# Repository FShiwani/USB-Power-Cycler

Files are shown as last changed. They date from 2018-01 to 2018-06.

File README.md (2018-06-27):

# USB Power Cycler
A design using an ATMega328P-PU microcontroller to delay the supply of power to an external USB device. It is useful for sensitive USB devices that cannot handle rapid switches in power.

## Purpose
The reason behind the design was to delay the start up of a USB car handsfree receiver that would stop functioning due to power being cycling to the device when switching from the ACC to ON ignition states.

## Design Information
The choice of the microcontroller may seem a slightly too advanced for this project however due to it's popularity and the fact that the Arduino Uno boards use the exact same MCU I chose it to allow a smooth transition between my Arduino prototype over to an independant MCU using the internal 8MHz clock. Depending on how you source your ATMega328P-PU it may come preloaded with a bootloader designed for a 16MHz external crystal such as in the Arduino Uno or it may come with no bootloader burned at all. Either way, you will need to use a different bootloader with the approparite fuses enabled to use the internal clock. More information can be found [here](https://www.arduino.cc/en/Tutorial/ArduinoToBreadboard). An 8-bit DIP switch is used to control the delay time. Values from 0 to 255 seconds are possible with the 8-bits and must be used in binary form. The firmware loaded on the MCU is relatively straight forward and an Arduino sketch is also available. The FDN340P is a logic level p-channel MOSFET is being used as a high side switch for the 5V rail.

## Schematic View
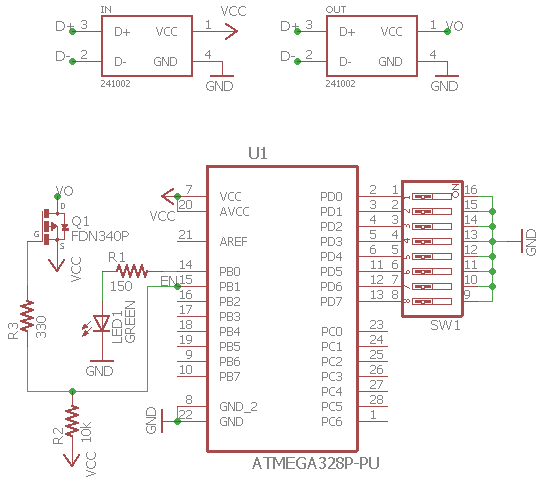
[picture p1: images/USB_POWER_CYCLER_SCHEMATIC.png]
Schematic

## Board View
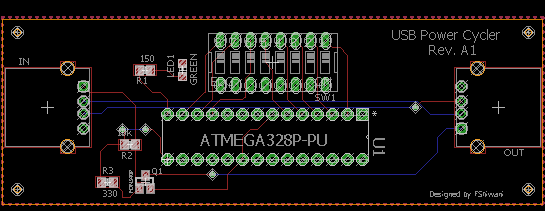
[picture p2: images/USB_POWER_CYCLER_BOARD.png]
Board


## Final Images
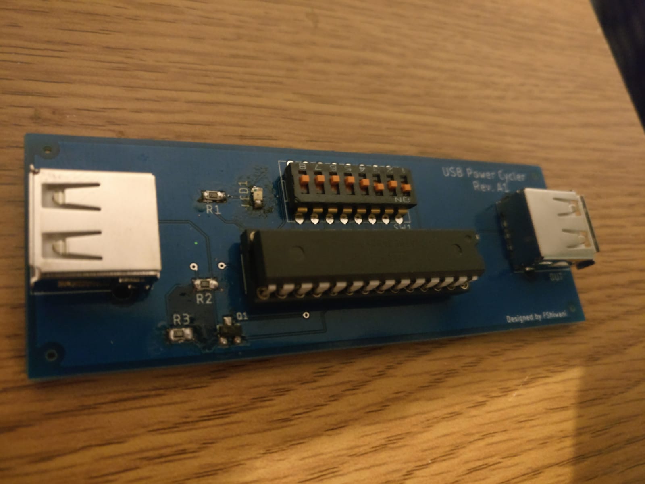
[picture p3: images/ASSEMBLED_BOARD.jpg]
Final Board

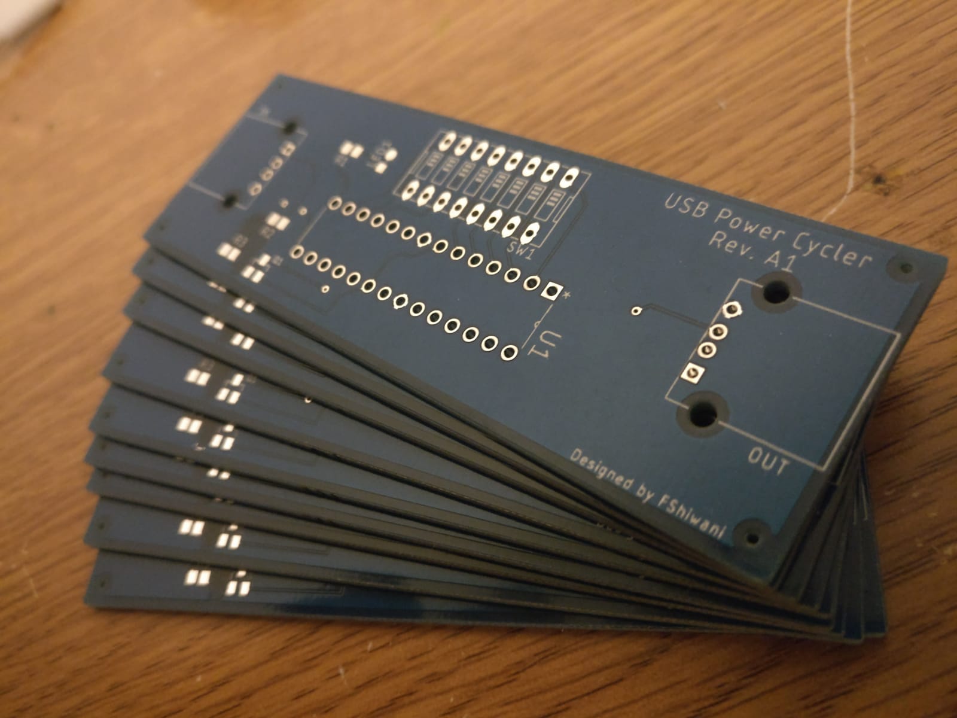
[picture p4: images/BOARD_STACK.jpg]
PCBs


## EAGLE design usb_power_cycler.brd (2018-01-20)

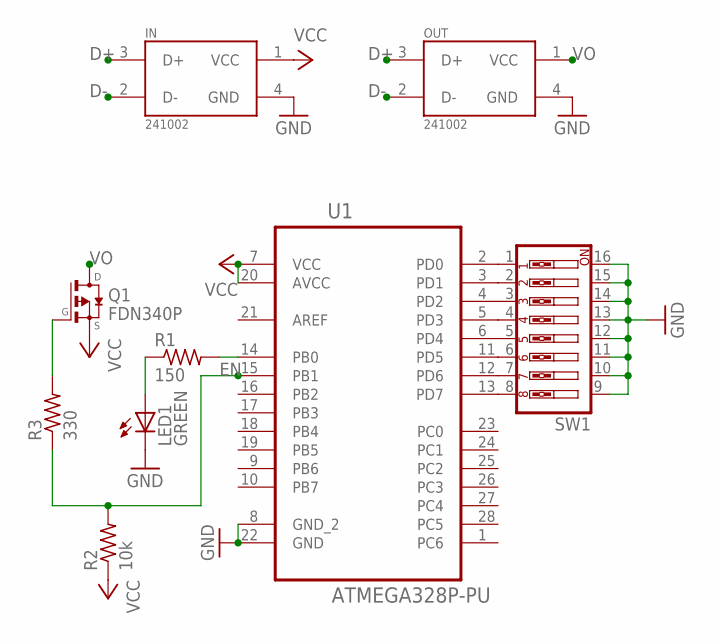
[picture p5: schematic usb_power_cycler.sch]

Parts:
IN: 241002; LUMBERG_2410_02
LED1: GREEN; CHIPLED_0805
OUT: 241002; LUMBERG_2410_02
Q1: FDN340P; SSOT-3
R1: 150; R0805
R2: 10k; R0805
R3: 330; R0805
SW1: SW_DIP-8; EDG-08
U1: ATMEGA328P-PU; DIP254P762X457-28

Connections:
D+: IN.3 (D+), OUT.3 (D+)
D-: IN.2 (D-), OUT.2 (D-)
EN: R2.2, R3.1, U1.15 (PB1)
GND: IN.4 (GND), LED1.C, OUT.4 (GND), SW1.9, SW1.10, SW1.11, SW1.12, SW1.13, SW1.14, SW1.15, SW1.16, U1.8 (GND_2), U1.22 (GND)
unnamed: LED1.A, R1.1
unnamed: SW1.1, U1.2 (PD0)
unnamed: SW1.2, U1.3 (PD1)
unnamed: SW1.3, U1.4 (PD2)
unnamed: SW1.4, U1.5 (PD3)
unnamed: SW1.5, U1.6 (PD4)
unnamed: SW1.6, U1.11 (PD5)
unnamed: SW1.7, U1.12 (PD6)
unnamed: SW1.8, U1.13 (PD7)
unnamed: R1.2, U1.14 (PB0)
unnamed: Q1.1 (G), R3.2
VCC: IN.1 (VCC), Q1.2 (S), R2.1, U1.7 (VCC), U1.20 (AVCC)
VO: OUT.1 (VCC), Q1.3 (D)

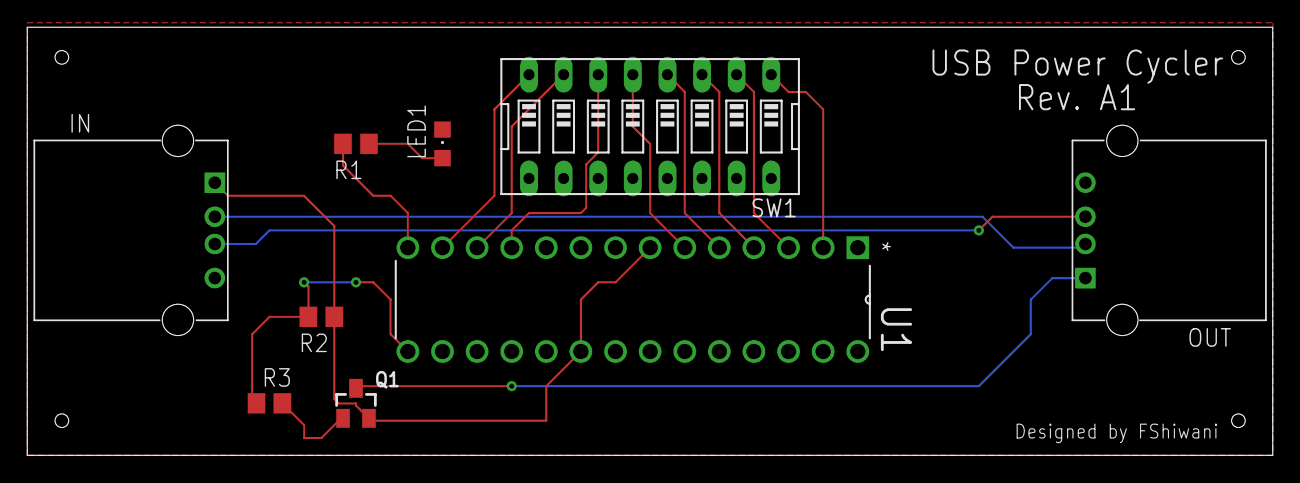
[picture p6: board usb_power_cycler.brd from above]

Board: 2 copper layers, 91.4 x 31.4 mm, 9 parts (0 on the bottom side), 17 nets.

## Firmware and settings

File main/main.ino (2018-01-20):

// ▒█░▒█ ▒█▀▀▀█ ▒█▀▀█ ░░ ▒█▀▀█ ▒█▀▀▀█ ▒█░░▒█ ▒█▀▀▀ ▒█▀▀█ ░░ ▒█▀▀█ ▒█░░▒█ ▒█▀▀█ ▒█░░░ ▒█▀▀▀ ▒█▀▀█ 
// ▒█░▒█ ░▀▀▀▄▄ ▒█▀▀▄ ▀▀ ▒█▄▄█ ▒█░░▒█ ▒█▒█▒█ ▒█▀▀▀ ▒█▄▄▀ ▀▀ ▒█░░░ ▒█▄▄▄█ ▒█░░░ ▒█░░░ ▒█▀▀▀ ▒█▄▄▀ 
// ░▀▄▄▀ ▒█▄▄▄█ ▒█▄▄█ ░░ ▒█░░░ ▒█▄▄▄█ ▒█▄▀▄█ ▒█▄▄▄ ▒█░▒█ ░░ ▒█▄▄█ ░░▒█░░ ▒█▄▄█ ▒█▄▄█ ▒█▄▄▄ ▒█░▒█ 
/* --------------------------------------------------------------------------------------------------------------------------------------------
 *  Project: USB Power Cycler
 *  Author: Fahd Shiwani
 *  Version: Rev. A
 *  Target Microncontroller: ATMega328P-PU
 * --------------------------------------------------------------------------------------------------------------------------------------------
 */

// Pin Declarations
#define ACTIVITY_LED_PIN 8 // PB0
#define ENABLE_PIN 9 // PB1
#define SW_PIN_1 0 // PD0
#define SW_PIN_2 1 // PD1
#define SW_PIN_3 2 // PD2
#define SW_PIN_4 3 // PD3
#define SW_PIN_5 4 // PD4
#define SW_PIN_6 5 // PD5
#define SW_PIN_7 6 // PD6
#define SW_PIN_8 7 // PD7

unsigned int SW_STATE[8]; // DIP switch state

// function to read digital pins for DIP switch.
void readSWState(int SW_STATE[]){
  SW_STATE[0] = !digitalRead(SW_PIN_1); // MSB
  SW_STATE[1] = !digitalRead(SW_PIN_2);
  SW_STATE[2] = !digitalRead(SW_PIN_3);
  SW_STATE[3] = !digitalRead(SW_PIN_4);
  SW_STATE[4] = !digitalRead(SW_PIN_5);
  SW_STATE[5] = !digitalRead(SW_PIN_6);
  SW_STATE[6] = !digitalRead(SW_PIN_7);
  SW_STATE[7] = !digitalRead(SW_PIN_8); // LSB
}

// function to convert from binary switch state values to integer delay.
int convertSW(int SW_STATE[]){
  unsigned int delay = 0;
  
  for(int i=0; i<8; i++){
    delay = (delay << 1) + SW_STATE[i];
  }
  Serial.print("Requested Delay: ");
  Serial.print(delay);
  Serial.print(" seconds");
  return delay;
}

void setup() {
  Serial.begin(9600);
  
  // Intializing Pins
  pinMode(ACTIVITY_LED_PIN, OUTPUT);
  pinMode(ENABLE_PIN, OUTPUT);
  pinMode(SW_PIN_1, INPUT_PULLUP); // enabling internal pull-ups.
  pinMode(SW_PIN_2, INPUT_PULLUP);
  pinMode(SW_PIN_3, INPUT_PULLUP);
  pinMode(SW_PIN_4, INPUT_PULLUP);
  pinMode(SW_PIN_5, INPUT_PULLUP);
  pinMode(SW_PIN_6, INPUT_PULLUP);
  pinMode(SW_PIN_7, INPUT_PULLUP);
  pinMode(SW_PIN_8, INPUT_PULLUP);

  readSWState(SW_STATE);
  digitalWrite(ACTIVITY_LED_PIN, HIGH);
  digitalWrite(ENABLE_PIN, HIGH); // active-low enable.
  delay(convertSW(SW_STATE)*1000L); // converted to milliseconds
  digitalWrite(ENABLE_PIN, LOW); 
  digitalWrite(ACTIVITY_LED_PIN, LOW);
}

void loop() {

}
